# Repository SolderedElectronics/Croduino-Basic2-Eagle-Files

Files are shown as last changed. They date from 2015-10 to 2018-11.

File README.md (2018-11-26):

# Croduino Basic2 Eagle Files
## Image
Croduino Basic2 image
[Croduino Basic2(100025)](https://e-radionica.com/en/croduino-basic2.html)

## Description and details
Croduino Basic2 is 100% Arduino compatible board made in EU(Croatia), created to promote Arduino culture in Croatia(well, it's named CROduino). Install Arduino software, plug it into USB and start DIY-ing!

It has even more analog inputs than Arduino Uno, features Silabs USB to UART bridge and built-in voltage regulator. The main difference from original Arduino and Croduino is size. Croduino is just 5cm x 3cm which makes it very easy to implement into projects. More:

- Atmega328 microcontroller(32kB flash, 2kB RAM, 1kB EEPROM)
- Silabs CP2102 USB to UART bridge
- 22 I/O pins, 14 digital I/O, 6 PWM, 8 analog pins
- Size only 3 x 5cm (1.2 x 2 inch)
- LED light on the 13th pin
- Voltage regulator for possibility of external charging
- Protection fuse
- Breadboard friendly
- Made in Croatia
- Free lifetime technical support at techsupport@e-radionica.com

Microcontroller on-board is loaded with Arduino Optiboot bootloader.

## Repository content
This repo contains Cadsoft Eagle .sch and .brd files for Croduino Basic2 board. It also contains schematic in .pdf created from .sch Eagle file. 
Files have been arranged into folders for navigating between different versions of board. 
Tip: layer 200 shows top silkscreen and layer 208 should be bottom silkscreen. tParts and bParts layers are not used.

## Docs
- [Croduino Basic product page] (https://e-radionica.com/en/croduino-basic2.html)
- [Croduino lessons - on croatian language] (https://vimeo.com/channels/croduino)

## Board versions
- v0.9b - test version, same copper, different silkscreen
- v1.0 REV A - inital published version 

## License info
This product is open-source. Yay!
For any tech questions, contact us at techsupport@e-radionica.com
If you find an Issue, please open one at GitHub. If you can improve our product, fork us.

e-radionica.com Team.

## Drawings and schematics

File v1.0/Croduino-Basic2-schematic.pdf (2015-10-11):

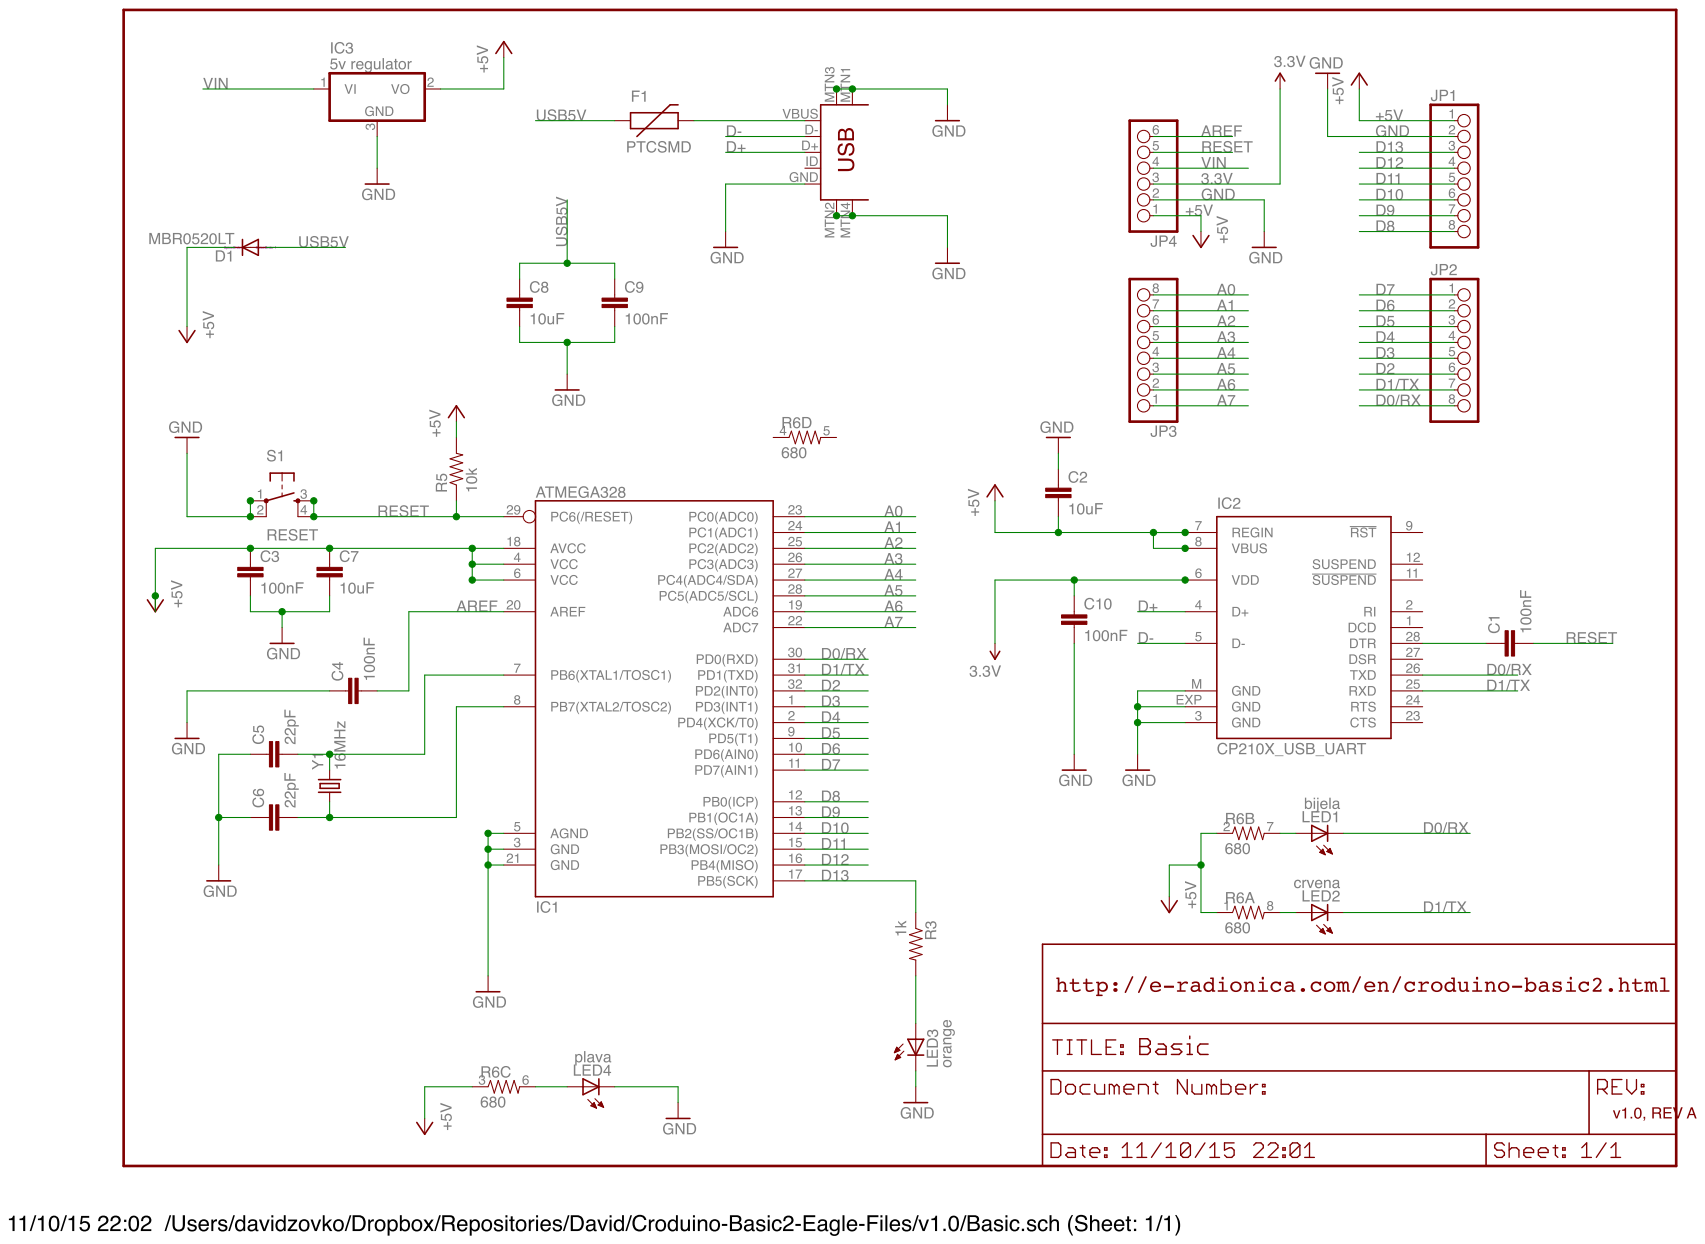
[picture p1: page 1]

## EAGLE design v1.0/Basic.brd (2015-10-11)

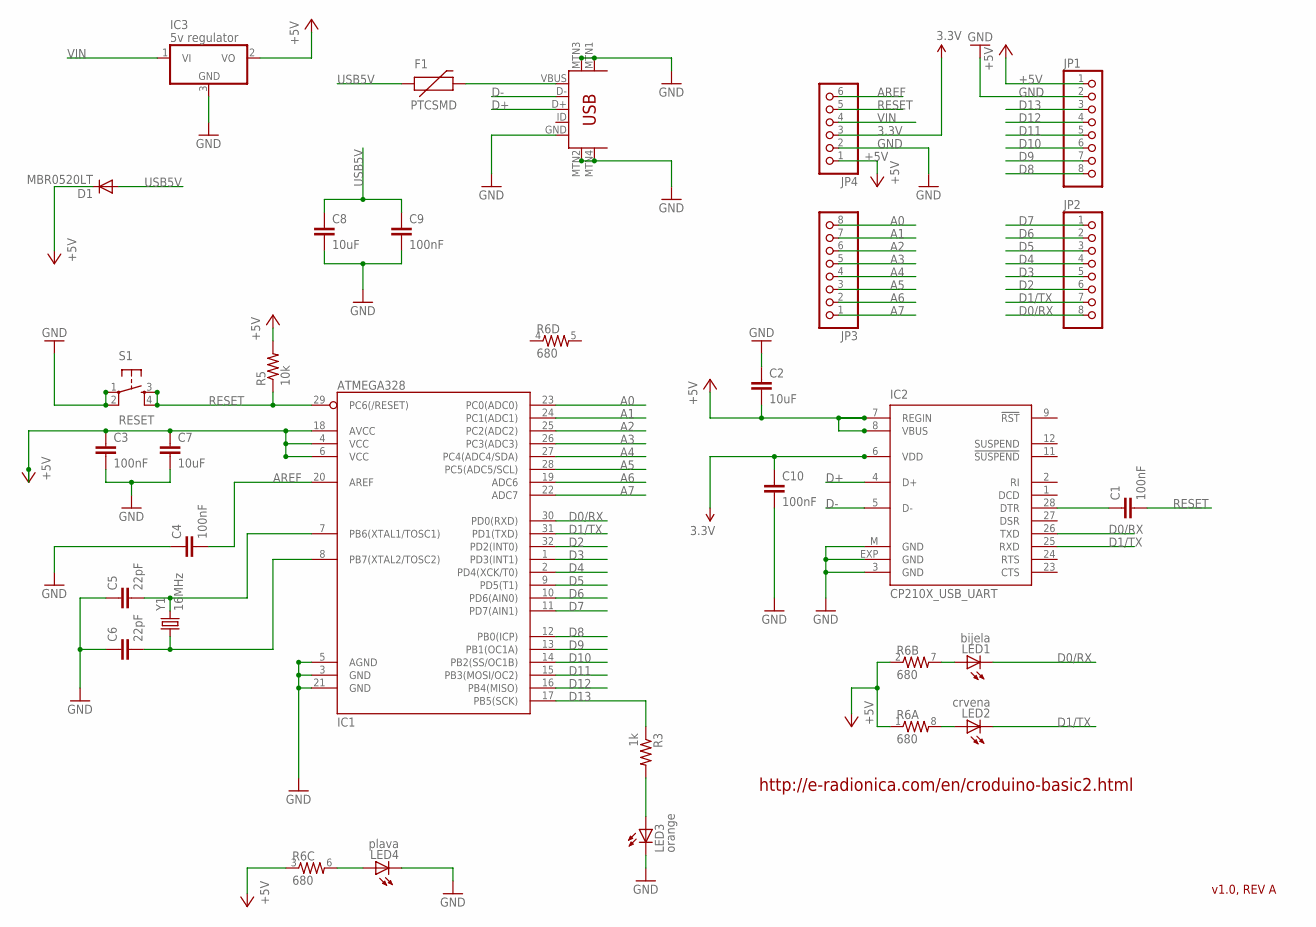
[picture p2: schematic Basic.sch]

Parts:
C1, C3, C4, C9, C10: 100nF; 0603-CAP
C2, C7, C8: 10uF; C3216
C5, C6: 22pF; 0603-CAP
D1: MBR0520LT; SOD123
F1: PTCSMD; PTC-1206
IC1: ATMEGA328; TQFP32-08
IC2: CP210X_USB_UART; MLP28
IC3: 5v regulator; TO252
JP1, JP2, JP3: PINHD-1X8BIG; 1X08-BIG
JP4: PINHD-1X6B; 1X06-BIG
LED1: bijela; CHIP-LED0805
LED2: crvena; CHIP-LED0805
LED3: orange; CHIP-LED0805
LED4: plava; CHIP-LED0805
R3: 1k; 0603-RES
R5: 10k; 0603-RES
R6: 680; 0603-ARV
S1: RESET; TACTILE_SWITCH_SMD
U1: USB-MINIB
Y1: 16MHz; CRYSTAL-SMD-5X3

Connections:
3.3V: C10.1, IC2.6 (VDD), JP4.3
+5V: C2.2, C3.1, C7.1, D1.C, IC1.4 (VCC), IC1.6 (VCC), IC1.18 (AVCC), IC2.7 (REGIN), IC2.8 (VBUS), IC3.2 (VO), JP1.1, JP4.1, R5.2, R6.1, R6.2 (1), R6.3 (1)
A0: IC1.23 (PC0(ADC0)), JP3.8
A1: IC1.24 (PC1(ADC1)), JP3.7
A2: IC1.25 (PC2(ADC2)), JP3.6
A3: IC1.26 (PC3(ADC3)), JP3.5
A4: IC1.27 (PC4(ADC4/SDA)), JP3.4
A5: IC1.28 (PC5(ADC5/SCL)), JP3.3
A6: IC1.19 (ADC6), JP3.2
A7: IC1.22 (ADC7), JP3.1
AREF: C4.2, IC1.20 (AREF), JP4.6
CRYSTAL1: C5.2, IC1.7 (PB6(XTAL1/TOSC1)), Y1.3 (2)
CRYSTAL2: C6.2, IC1.8 (PB7(XTAL2/TOSC2)), Y1.1
D0/RX: IC1.30 (PD0(RXD)), IC2.26 (TXD), JP2.8, LED1.C
D1/TX: IC1.31 (PD1(TXD)), IC2.25 (RXD), JP2.7, LED2.C
D2: IC1.32 (PD2(INT0)), JP2.6
D3: IC1.1 (PD3(INT1)), JP2.5
D4: IC1.2 (PD4(XCK/T0)), JP2.4
D5: IC1.9 (PD5(T1)), JP2.3
D6: IC1.10 (PD6(AIN0)), JP2.2
D7: IC1.11 (PD7(AIN1)), JP2.1
D8: IC1.12 (PB0(ICP)), JP1.8
D9: IC1.13 (PB1(OC1A)), JP1.7
D10: IC1.14 (PB2(SS/OC1B)), JP1.6
D11: IC1.15 (PB3(MOSI/OC2)), JP1.5
D12: IC1.16 (PB4(MISO)), JP1.4
D13: IC1.17 (PB5(SCK)), JP1.3, R3.1
D+: IC2.4 (D+), U1.D+
D-: IC2.5 (D-), U1.D-
GND: C2.1, C3.2, C4.1, C5.1, C6.1, C7.2, C8.2, C9.2, C10.2, IC1.3 (GND), IC1.5 (AGND), IC1.21 (GND), IC2.3 (GND), IC2.EXP (GND), IC2.M (GND), IC3.3 (GND), JP1.2, JP4.2, LED3.C, LED4.C, S1.1, S1.2, U1.GND, U1.MTN1 (MTN2), U1.MTN2 (MTN3), U1.MTN3 (MTN1), U1.MTN4
unnamed: LED1.A, R6.7 (2)
unnamed: LED2.A, R6.8 (2)
unnamed: F1.2, U1.VBUS
NAR_LED: LED3.A, R3.2
PLV_LED: LED4.A, R6.6 (2)
RESET: C1.2, IC1.29 (PC6(/RESET)), JP4.5, R5.1, S1.3, S1.4
RST_PRIJE_KOND: C1.1, IC2.28 (DTR)
USB5V: C8.1, C9.1, D1.A, F1.1
VIN: IC3.1 (VI), JP4.4

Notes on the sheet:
v1.0, REV A
http://e-radionica.com/en/croduino-basic2.html

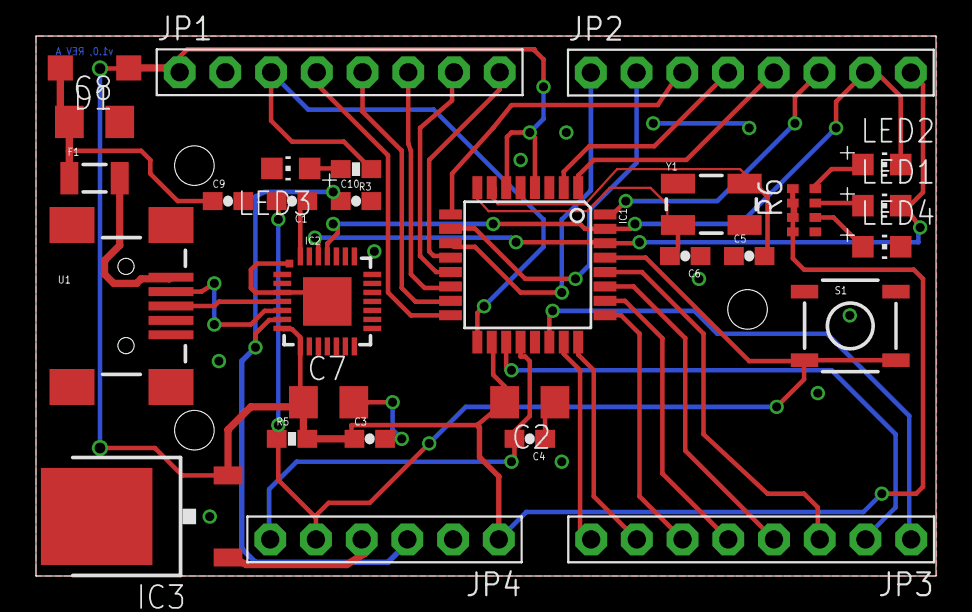
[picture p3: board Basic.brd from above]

Board: 2 copper layers, 50.0 x 30.0 mm, 38 parts (0 on the bottom side), 39 nets.

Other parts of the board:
U$1: BASIC2_LED
U$2: BASIC2_ANALOG
U$3: BASIC2_ANALOG2
U$4: BASIC2_DIGITAL
U$5: BASIC2_DIGITAL2
U$6, U$7: NOVI_LOGO-4MM
U$8: CRODUINO_BASIC2
U$9: BASIC2_BOTTOM

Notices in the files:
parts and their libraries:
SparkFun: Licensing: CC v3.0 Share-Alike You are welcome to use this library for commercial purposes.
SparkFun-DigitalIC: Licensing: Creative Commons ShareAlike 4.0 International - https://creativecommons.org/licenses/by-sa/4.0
